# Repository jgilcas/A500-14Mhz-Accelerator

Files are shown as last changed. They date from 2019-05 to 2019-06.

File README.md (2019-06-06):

# A500-14Mhz-Accelerator
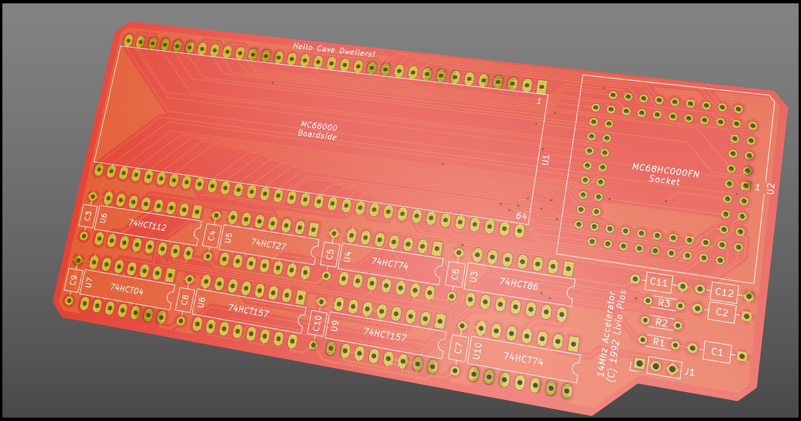
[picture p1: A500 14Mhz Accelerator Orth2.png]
A500 14Mhz Accelerator


Updated version of the infamous 14Mhz Accelerator by Livio Plos - stackable with the 8MB FastRAM board. 

Yeah i know, there's a load of accelerators out there (the TF520/530/534 by the exceptionally talented Stephen 'TerribleFire' Leary being the most prominent) that are much, much more impressive than this - but this has the following things going for it:

1) It's 100% through hole soldering, no SMT parts - easy for a beginner or for someone with shaky hands like me.
2) It's cheap to build
3) Uses simple logic gates - no fancy-schmancy CPLD/FPGA gubbins ;)
4) It's...err...it's...it's green (well, it can be if you choose that colour solder mask!)

Stacking with the 8MB FastRAM board works a treat although clearance with the top case in an A500 miiiiight be an issue. 

Uses 68HC000 chips, these run a lot cooler than the originals, and can be clocked high, without the need of a heatsink.

# Bill of Materials

--== COMING SOON ==--

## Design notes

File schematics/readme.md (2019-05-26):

No special footprints or libraries required - standard KiCad libraries will suffice.

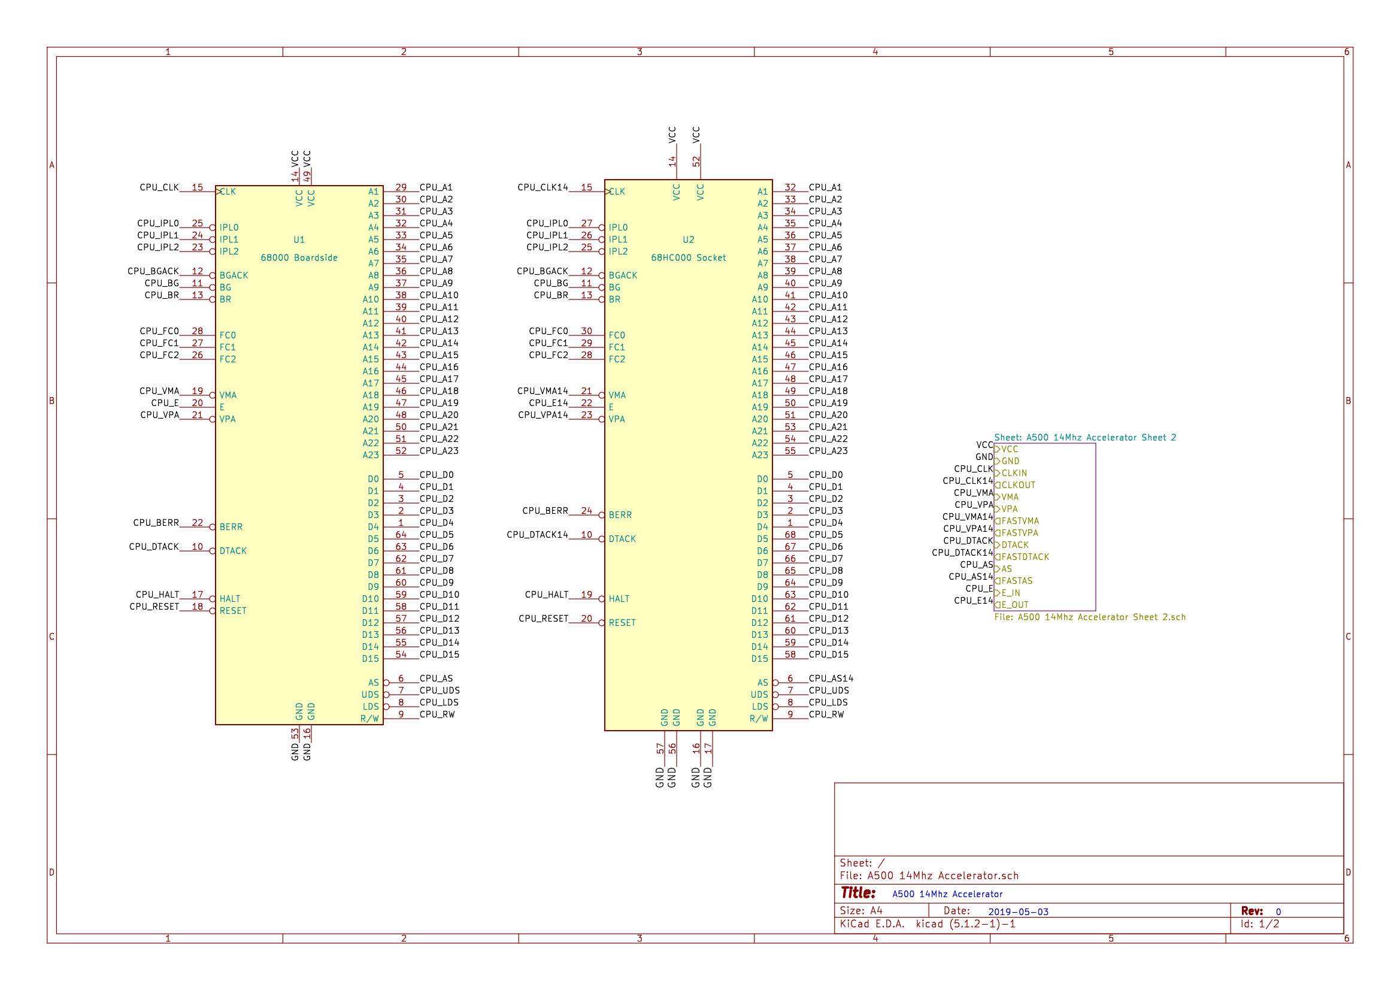
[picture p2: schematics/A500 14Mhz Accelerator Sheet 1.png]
A500 14Mhz Accelerator Schematic Page 1


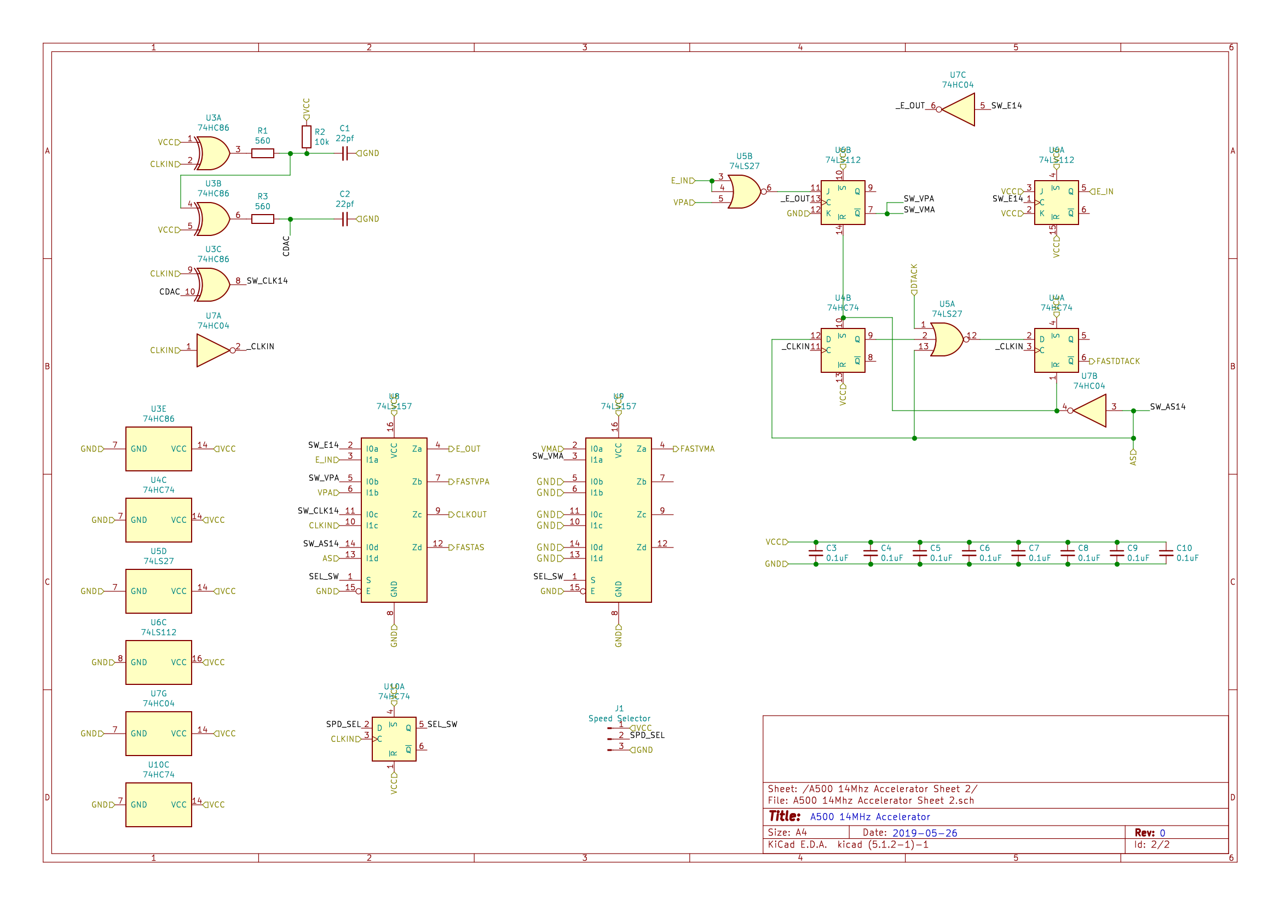
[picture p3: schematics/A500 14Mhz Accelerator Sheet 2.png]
A500 14Mhz Accelerator Schematic Page 2


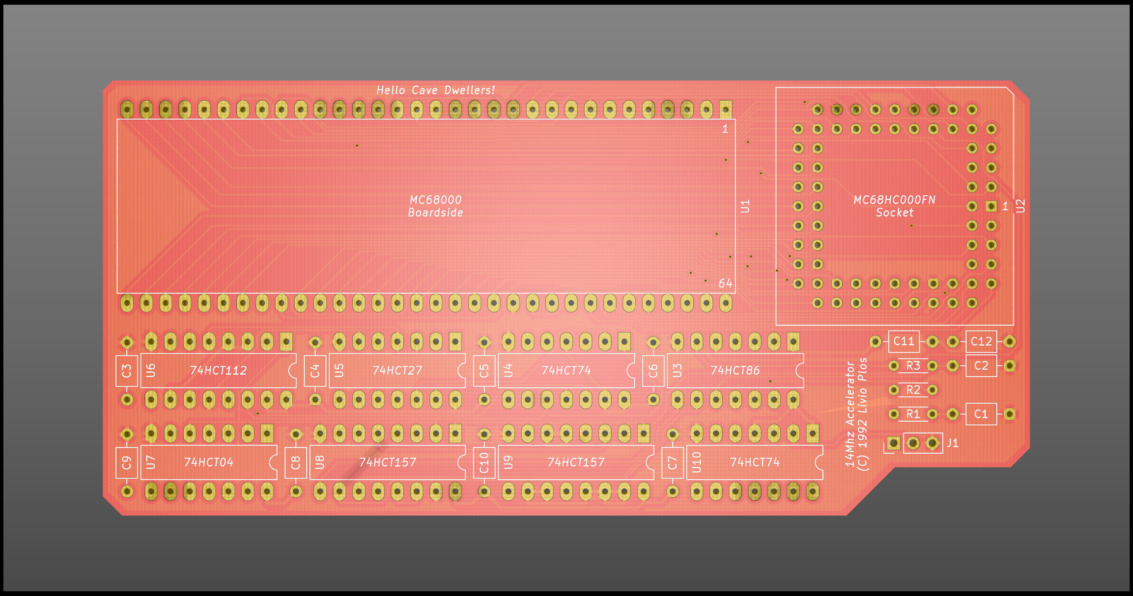
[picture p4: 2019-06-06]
A500 14Mhz Accelerator Top0.png

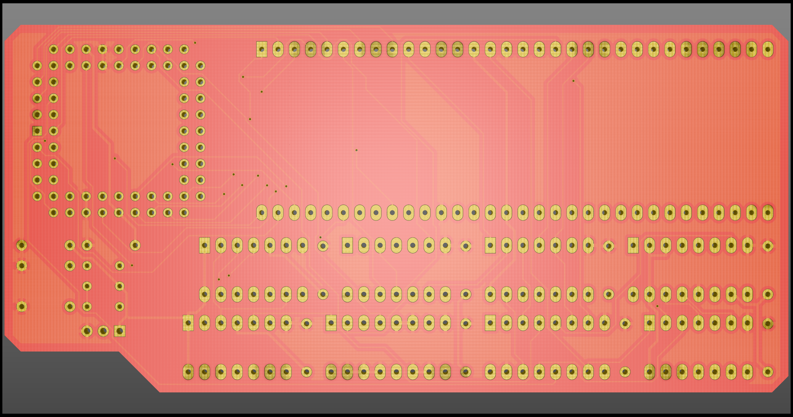
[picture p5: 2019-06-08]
A500 14Mhz Accelerator Bottom1.png

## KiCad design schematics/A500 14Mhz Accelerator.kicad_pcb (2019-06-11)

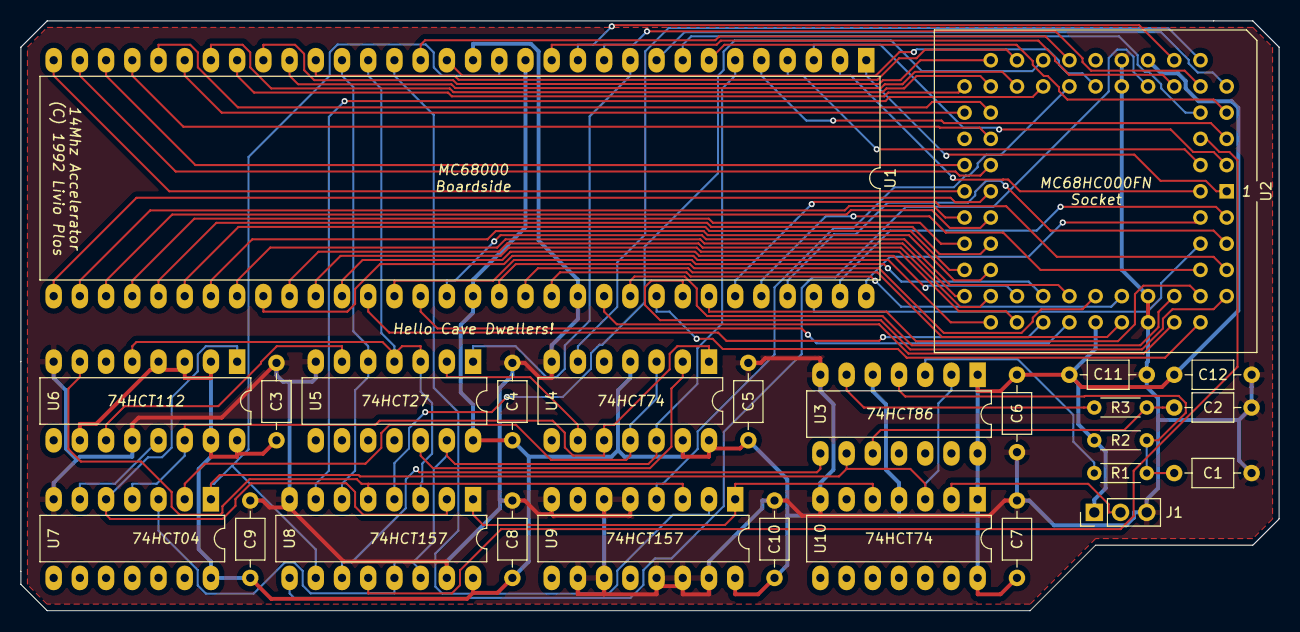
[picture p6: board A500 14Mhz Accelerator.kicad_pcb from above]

Board: 2 copper layers, 121.9 x 57.1 mm, 26 parts (0 on the bottom side), 83 nets.

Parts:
C1, C2: 22pf; C_Axial_L3.8mm_D2.6mm_P7.50mm_Horizontal
C3, C4, C5, C6, C7, C8, C9, C10, C11, C12: 0.1uF; C_Axial_L3.8mm_D2.6mm_P7.50mm_Horizontal
J1: Speed Selector; PinHeader_1x03_P2.54mm_Vertical
R1, R3: 560; R_Axial_DIN0204_L3.6mm_D1.6mm_P5.08mm_Horizontal
R2: 10k; R_Axial_DIN0204_L3.6mm_D1.6mm_P5.08mm_Horizontal
U1: 68000 Boardside; DIP-64_W22.86mm_LongPads
U2: 68HC000 Socket; PLCC-68_THT-Socket
U3: 74HC86; DIP-14_W7.62mm_LongPads
U4, U10: 74HC74; DIP-14_W7.62mm_LongPads
U5: 74LS27; DIP-14_W7.62mm_LongPads
U6: 74LS112; DIP-16_W7.62mm_LongPads
U7: 74HC04; DIP-14_W7.62mm_LongPads
U8, U9: 74LS157; DIP-16_W7.62mm_LongPads

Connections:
/A500 14Mhz Accelerator Sheet 2/CDAC: C2.2, R3.1, U3.10
/A500 14Mhz Accelerator Sheet 2/SEL_SW: U8.1, U9.1, U10.5
/A500 14Mhz Accelerator Sheet 2/SPD_SEL: J1.2, U10.2
/A500 14Mhz Accelerator Sheet 2/SW_CLK14: U3.8, U8.11
/A500 14Mhz Accelerator Sheet 2/SW_E14: U6.1, U7.5, U8.2
/A500 14Mhz Accelerator Sheet 2/SW_VMA: U6.7, U8.5, U9.3
/A500 14Mhz Accelerator Sheet 2/_CLKIN: U4.3, U4.11, U7.2
/A500 14Mhz Accelerator Sheet 2/_E_OUT: U6.13, U7.6
/CPU_A1: U1.29, U2.32
/CPU_A2: U1.30, U2.33
/CPU_A3: U1.31, U2.34
/CPU_A4: U1.32, U2.35
/CPU_A5: U1.33, U2.36
/CPU_A6: U1.34, U2.37
/CPU_A7: U1.35, U2.38
/CPU_A8: U1.36, U2.39
/CPU_A9: U1.37, U2.40
/CPU_A10: U1.38, U2.41
/CPU_A11: U1.39, U2.42
/CPU_A12: U1.40, U2.43
/CPU_A13: U1.41, U2.44
/CPU_A14: U1.42, U2.45
/CPU_A15: U1.43, U2.46
/CPU_A16: U1.44, U2.47
/CPU_A17: U1.45, U2.48
/CPU_A18: U1.46, U2.49
/CPU_A19: U1.47, U2.50
/CPU_A20: U1.48, U2.51
/CPU_A21: U1.50, U2.53
/CPU_A22: U1.51, U2.54
/CPU_A23: U1.52, U2.55
/CPU_AS: U1.6, U4.12, U5.13, U7.3, U8.13, U8.14
/CPU_AS14: U2.6, U8.12
/CPU_BERR: U1.22, U2.24
/CPU_BG: U1.11, U2.11
/CPU_BGACK: U1.12, U2.12
/CPU_BR: U1.13, U2.13
/CPU_CLK: U1.15, U3.2, U3.9, U7.1, U8.10, U10.3
/CPU_CLK14: U2.15, U8.9
/CPU_D0: U1.5, U2.5
/CPU_D1: U1.4, U2.4
/CPU_D2: U1.3, U2.3
/CPU_D3: U1.2, U2.2
/CPU_D4: U1.1, U2.1
/CPU_D5: U1.64, U2.68
/CPU_D6: U1.63, U2.67
/CPU_D7: U1.62, U2.66
/CPU_D8: U1.61, U2.65
/CPU_D9: U1.60, U2.64
/CPU_D10: U1.59, U2.63
/CPU_D11: U1.58, U2.62
/CPU_D12: U1.57, U2.61
/CPU_D13: U1.56, U2.60
/CPU_D14: U1.55, U2.59
/CPU_D15: U1.54, U2.58
/CPU_DTACK: U1.10, U5.1
/CPU_DTACK14: U2.10, U4.6
/CPU_E: U1.20, U5.3, U5.4, U6.5, U8.3
/CPU_E14: U2.22, U8.4
/CPU_FC0: U1.28, U2.30
/CPU_FC1: U1.27, U2.29
/CPU_FC2: U1.26, U2.28
/CPU_HALT: U1.17, U2.19
/CPU_IPL0: U1.25, U2.27
/CPU_IPL1: U1.24, U2.26
/CPU_IPL2: U1.23, U2.25
/CPU_LDS: U1.8, U2.8
/CPU_RESET: U1.18, U2.20
/CPU_RW: U1.9, U2.9
/CPU_UDS: U1.7, U2.7
/CPU_VMA: U1.19, U9.2
/CPU_VMA14: U2.21, U9.4
/CPU_VPA: U1.21, U5.5, U8.6
/CPU_VPA14: U2.23, U8.7
/GND: C1.1, C2.1, C3.2, C4.2, C5.2, C6.2, C7.2, C8.2, C9.2, C10.2, C11.2, C12.2, J1.3, U1.16, U1.53, U2.16, U2.17, U2.56, U2.57, U3.7, U4.7, U5.7, U6.8, U6.12, U7.7, U8.8, U8.15, U9.5, U9.6, U9.8, U9.10, U9.11, U9.13, U9.14, U9.15, U10.7
/VCC: C3.1, C4.1, C5.1, C6.1, C7.1, C8.1, C9.1, C10.1, C11.1, C12.1, J1.1, R2.1, U1.14, U1.49, U2.14, U2.52, U3.1, U3.5, U3.14, U4.4, U4.13, U4.14, U5.14, U6.2, U6.3, U6.4, U6.10, U6.15, U6.16, U7.14, U8.16, U9.16, U10.1, U10.4, U10.14
unnamed: C1.2, R1.1, R2.2, U3.4
unnamed: R1.2, U3.3
unnamed: R3.2, U3.6
unnamed: U4.1, U4.10, U6.14, U7.4
unnamed: U4.2, U5.12
unnamed: U4.9, U5.2
unnamed: U5.6, U6.11

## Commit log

2019-05-26 Add files via upload
    Update the silkscreen
2019-06-06 Respin to add copper fill
    Moved components around for better decoupling on the caps, added copper fill
    [A500 14Mhz Accelerator Sheet 2.sch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]
2019-06-08 Re-doing the copper fill
    [A500 14Mhz Accelerator-B_Cu.gbr, A500 14Mhz Accelerator-B_Mask.gbr, A500 14Mhz Accelerator-B_SilkS.gbr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]
2019-06-11 Reroute with correct socket
    [A500 14Mhz Accelerator-B_Cu.gbr, A500 14Mhz Accelerator-B_Mask.gbr, A500 14Mhz Accelerator-B_SilkS.gbr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]

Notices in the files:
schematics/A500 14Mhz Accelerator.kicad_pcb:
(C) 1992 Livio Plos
